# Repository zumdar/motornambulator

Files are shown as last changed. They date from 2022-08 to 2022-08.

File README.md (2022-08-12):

# quadmotornambulator 

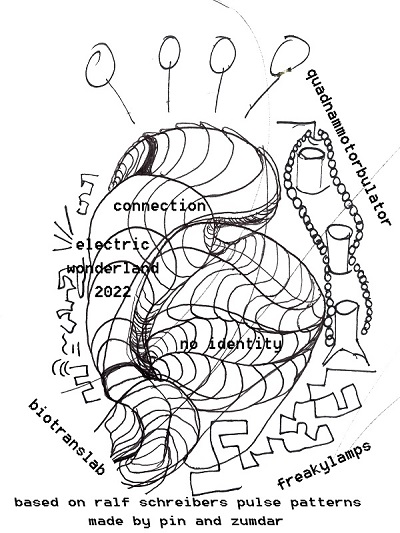
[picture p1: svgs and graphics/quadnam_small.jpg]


a collaboration between [pin](http://paulapin.net/) and [zumdar](https://freakylamps.com/) at [Electric Wonderland 2022](https://www.electric-wonderland.eu/)

motors are people too

this is a non-identity 4x motor record and playback machine based on [ralf schreiber](http://www.ralfschreiber.com/)'s pulse pattern workshop. specifically, we are taking the 'attiny85 record + play', multiplying it times 4,put it on a single sided PCB, and etching it!
ralf's original circuit and code found here: http://www.ralfschreiber.com/share/pulseandpatterns.html

code for the attiny can be found at ralfs website above 

# notes for recreation
included in this repo is the kicad files, graphics, and final svg and pdfs for making the transparency and board etch.

custom footprints were made to make the pads larger for easier etching and soldering. those footprints can be found in the included william_custom.pretty folder. 

# documentation

play vid (https://youtu.be/qF2Il0cjl8Y)
VIDEO!
 

we etched the board on site at EW2022! 


user interface parts of the circuit are on the top, the rest are soldered on the bottom


part of the setup for the performance on 8/10/2022


motor madness

# TODO's

- button debouncing -- lots of button glitches makes it so it doesnt always record
- graphics displaying play and record buttons on pcb
- use one microcontroller? get more outputs?

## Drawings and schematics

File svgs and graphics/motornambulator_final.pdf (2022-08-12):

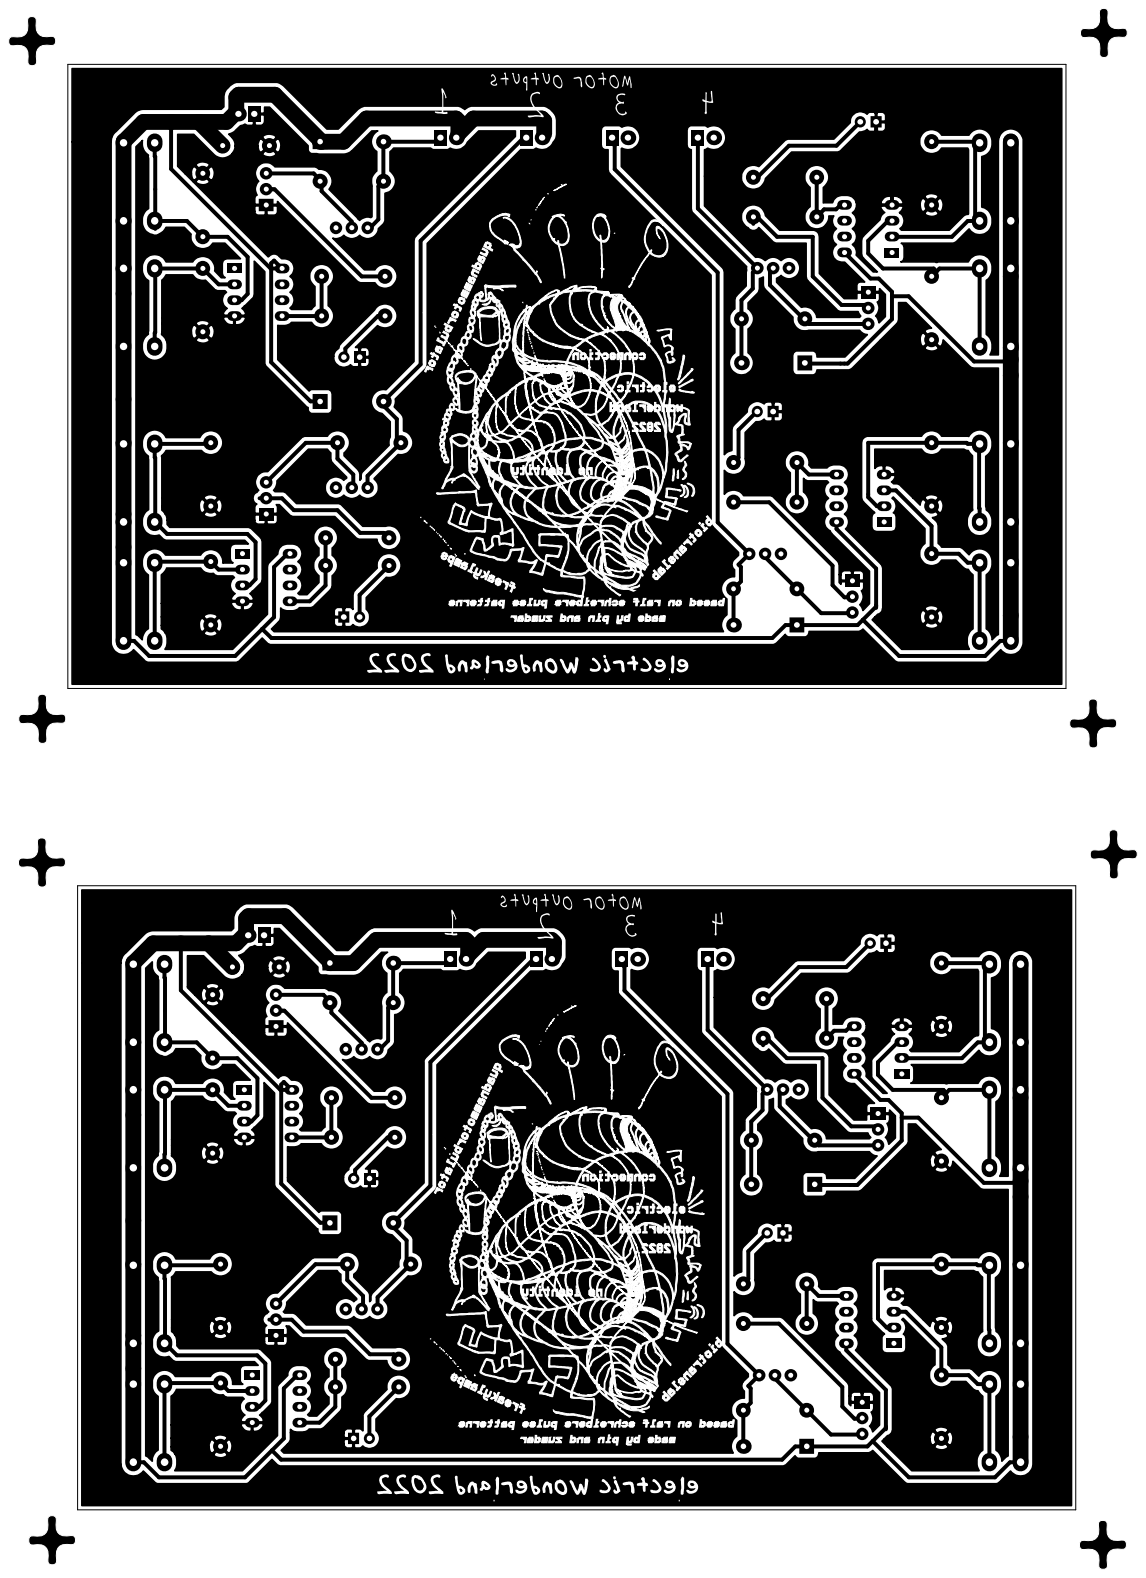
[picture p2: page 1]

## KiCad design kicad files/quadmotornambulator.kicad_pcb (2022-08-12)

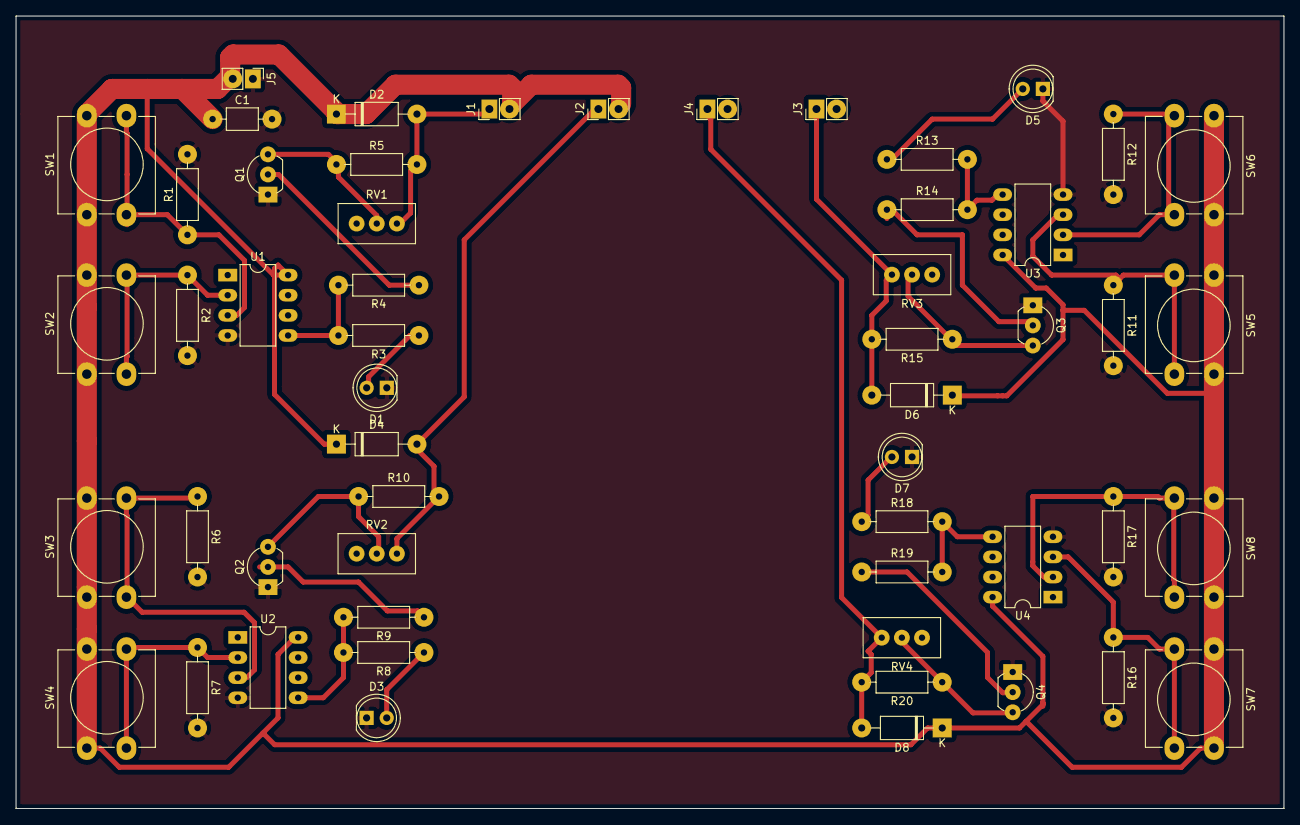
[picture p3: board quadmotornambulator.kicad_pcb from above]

Board: 2 copper layers, 160.0 x 100.0 mm, 54 parts (0 on the bottom side), 30 nets.

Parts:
C1: 470u; C_Axial_L3.8mm_D2.6mm_P7.50mm_Horizontal_BIG
D1, D3, D5, D7: LED; LED_D5.0mm
D2, D4, D6, D8: 1n4841; D_A-405_P10.16mm_Horizontal_BIG
J1: motor1 out; PinHeader_1x02_P2.54mm_Vertical_BIG
J2: motor2 out; PinHeader_1x02_P2.54mm_Vertical_BIG
J3: motor3 out; PinHeader_1x02_P2.54mm_Vertical_BIG
J4: motor4 out; PinHeader_1x02_P2.54mm_Vertical_BIG
J5: Conn_01x02_Male; PinHeader_1x02_P2.54mm_Vertical_BIG
Q1, Q2, Q3, Q4: 2N3904; TO-92_Inline_Wide_BIG
R1, R2, R6, R7, R11, R12, R16, R17: 10k; R_Axial_DIN0207_L6.3mm_D2.5mm_P10.16mm_Horizontal_BIG
R3, R4, R8, R9, R13, R14, R18, R19: 1k; R_Axial_DIN0207_L6.3mm_D2.5mm_P10.16mm_Horizontal_BIG
R5, R10, R15, R20: 120; R_Axial_DIN0207_L6.3mm_D2.5mm_P10.16mm_Horizontal_BIG
RV1, RV2, RV3, RV4: 1k; Potentiometer_Bourns_3296W_Vertical_BIG
SW1, SW2, SW3, SW4, SW5, SW6, SW7, SW8: SW_SPST; SW_PUSH-12mm_Wuerth-430476085716
U1, U2, U3, U4: ATtiny85-20PU; DIP-8_W7.62mm_LongPads

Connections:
+5V: C1.1, D2.1, D4.1, D6.1, D8.1, J1.2, J2.2, J3.2, J4.2, J5.2, SW1.1, SW2.1, SW3.1, SW4.1, SW5.1, SW6.1, SW7.1, SW8.1, U1.8, U2.8, U3.8, U4.8
GND: C1.2, D1.1, D3.1, D5.1, D7.1, J5.1, Q1.1, Q2.1, Q3.1, Q4.1, R1.2, R2.2, R6.2, R7.2, R11.2, R12.2, R16.2, R17.2, U1.4, U2.4, U3.4, U4.4
unnamed: D1.2, R3.1
unnamed: D2.2, J1.1, R5.2, RV1.1
unnamed: D3.2, R8.1
unnamed: D4.2, J2.1, R10.2, RV2.1
unnamed: D5.2, R13.1
unnamed: D6.2, J3.1, R15.2, RV3.1
unnamed: D7.2, R18.1
unnamed: D8.2, J4.1, R20.2, RV4.1
unnamed: Q1.2, R4.1
unnamed: Q1.3, R5.1, RV1.2
unnamed: Q2.2, R9.1
unnamed: Q2.3, R10.1, RV2.2
unnamed: Q3.2, R14.1
unnamed: Q3.3, R15.1, RV3.2
unnamed: Q4.2, R19.1
unnamed: Q4.3, R20.1, RV4.2
unnamed: R1.1, SW1.2, U1.3
unnamed: R2.1, SW2.2, U1.2
unnamed: R3.2, R4.2, U1.5
unnamed: R6.1, SW3.2, U2.3
unnamed: R7.1, SW4.2, U2.2
unnamed: R8.2, R9.2, U2.5
unnamed: R11.1, SW5.2, U3.3
unnamed: R12.1, SW6.2, U3.2
unnamed: R13.2, R14.2, U3.5
unnamed: R16.1, SW7.2, U4.3
unnamed: R17.1, SW8.2, U4.2
unnamed: R18.2, R19.2, U4.5
